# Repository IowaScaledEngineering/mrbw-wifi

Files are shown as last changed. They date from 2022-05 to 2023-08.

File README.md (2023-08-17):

# The Iowa Scaled Engineering MRBW-WIFI ProtoThrottle Bridge

Wireless MRBus to WiFi (802.11) Bridge for ProtoThrottles

# Getting Started

If you're using an ESU CabControl system with the built-in wifi and default configuration (ssid of ESU-WIFI and default password), LNWI, MRC WiFi module, DCC-EX, or Steve Todd's rpi-jmri image, it should just work.  Plug it in, try it out.

If you're using JMRI or any non-default wifi parameters, you'll need to at least set the ssid, password, and mode configuration options.

# Configuration Options

## The Onboard Switches

| Switch | Label | Description |
|---|---|---|
| 1 | Base Addr 16 | Part of setting the ProtoThrottle base address.  Adds 16 to the value if on.  Total sum value of switches 1-5 (the group marked BASE ADDR) must match the base configured in the PT COMM menu. |
| 2 | Base Addr 8 | Part of setting the ProtoThrottle base address.  Adds 8 to the value if on. |
| 3 | Base Addr 4 | Part of setting the ProtoThrottle base address.  Adds 4 to the value if on. |
| 4 | Base Addr 2 | Part of setting the ProtoThrottle base address.  Adds 2 to the value if on. |
| 5 | Base Addr 1 | Part of setting the ProtoThrottle base address.  Adds 1 to the value if on. |
| 6 | A | Not used - for future expansion. |
| 7 | FR | Factory Reset.  If this switch is ON when the unit is powered up or resets, it will overwrite the config.txt file with the factory defaults. |
| 8 | BL | Boot Loader. This is used to upgrade the firmware on the mrbw-wifi.  See the "Firmware Upgrade" section for details on use.  Leave this off for normal operations. |

## Automagic Configuration

The mrbw-wifi, by default, should connect to a good number of things automagically.  ESU CabControl systems using the onboard wifi, Digitrax LNWIs, default DCC-EX builds, and Steve Todd's rpi-jmri images are supported out of the box with no configuration through auto-discovery.

## Manual Configuration

If you do need to configure something different, you'll need to edit the configuration file.  When plugged into a computer via the USB cord, the device presents a mass storage class drive, much like a flash/thumb drive.  On this drive is a single file - config.txt.  Open it with a text editor like Notepad or Notepad++ (or whatever the Mac equivalent is - I have no idea).

The file is just a normal key = value kind of configuration file.  Any line starting with a # is considered a comment and will be ignored.

So, for example, if I want to connect to my layout's network, I might put in three lines:

mode = withrottle
ssid = CRNW Wireless Net
password = TotallyNotMyPassword1

Here's a list of valid parameters in the config.txt file:

| Parameter | Description |
|---|---|
| ssid | If you need to explicitly connect to a wifi network, put its name here.  Do not use quotes or anything else, just the network name as a parameter, even if it has spaces. |
| password  | If you need to connect to a secured wifi network that you specified in the ssid parameter, specify the password here.  If your network specified in ssid does not have a password, just leave an empty value in the password field.  |
| mode | If an ssid is specified, the command station mode must be set.  If the ssid field is not set, the mode parameter can be used to restrict the sort of command station networks that the wifi will automatically discover.  Mode can be `withrottle`, `lnwi`, `dccex`, `esu` currently.  For JMRI, MRC, and most other WiThrottle-compatible servers, use `withrottle`.  For LNWIs, use `lnwi`.  For DCC-EX servers, use `dccex`.  For ESU CabControl or ECoS systems, use `esu`.  |
| serverIP  | Normally the wifi will use mDNS to discover where the server is located.  If for some reason mDNS service discovery does not work, you can explicitly specify the server IP here.  It should be in the form 1.2.3.4 |
| serverPort  | Normally the wifi will use mDNS to discover where the server is located.  If your server does not run on the standard port for the protocol and you have explicitly set the IP address with serverIP, then you should also set the port to connect on with this option. |
| hostname  | If you want the wifi to explicitly use a different hostname when it connects to the network, please specify it here.  By default, it will be mrbw-wifi-XXXX, where XXXX is the last two octets of the MAC address expressed as hexadecimal to make it unique. |
| fastClockSource  | For JMRI, fast time is sent over the withrottle connection.  If you want to send fast time from your JMRI server via the wifi bridge to your ProtoThrottles and/or ISE fast clock remote displays, set this to `cmdstn`.  To disable any fast time being broadcast by the wifi bridge, set it to `none` or omit the parameter entirely. |
| logLevel  | *Advanced Users Only* The wifi bridge exposes a virtual serial port on the USB interface that it uses to send diagnostic logging information about what it's doing.  logLevel controls the verbosity at a global level.  Options in order of increasing verbosity are  `error`, `warn`, `info`, `debug`.  By default, it's set to `info` if not specified.  Unless you're watching the logs and trying to help us debug a specific problem, there's no reason to use this parameter.  In addition, you can use `logLevelCommandStation`, `logLevelMRBus`, or `logLevelSystem` as key values to turn up logging on only a specific part of the code that's having an issue. |

# Firmware Upgrades

The mrbw-wifi is designed to be easily upgradable, both because I know I'm going to have bugs and we're going to add new functionality in the future.

For most users, you'll upgrade via the UF2 bootloader.  Hold the receiver with both hands while it's powered up and plugged into your computer via a USB cord.  Use your left hand to tap the reset button, and immediately flip the BL switch to ON while the LED is purple.  You have 1 second from when you hit the reset button to do this, otherwise the system will boot normally.

If you've done it successfully, a new drive will apear on your machine (named "MRBWWIFI") with three files in it:  current.uf2, index.htm, and info_uf2.txt.

Find the firmware you want to upgrade to (it should be a file ending in .uf2) and copy it to this drive.  The LED should blink yellow and the mrbw-wifi should reboot at the end.  It may throw some sort of error on the computer at the end of the copy - don't worry about that.  Once it's done, turn the BL switch back to off and then hit RESET again.  You should be able to verify a successful upgrade by checking the version on the startup screen matches the version you upgraded to.

# Credits

Credit where credit is due.  This project builds on other open source projects, and without them, this would have taken much, much longer.

First, a credit to Adafruit for developing the [tinyuf2 bootloader](https://github.com/adafruit/tinyuf2) for the ESP32-S2.  Super easy to use, super easy to modify.

Secondly, to Espressif and all the contributors to the Arduino framework for the ESP32 series.  The MRBW-WIFI code is a mix of native ESP-IDF calls and some Arduino stuff, which saved me days if not weeks of figuring out stuff like their WiFi and IP stack.  Eventually we'll get to all native ESP-IDF code, but for now it's an excellent compromise.

Thirdly, to Platform.IO.  Seriously, you guys rock.  A little hard to figure out in spots, particularly where it goes off the rails, but genuinely a huge timesaver for getting up to speed on ESP32 without spending weeks mucking about with trying to figure out setup.  While I wasn't a huge VSCode fan when I started, it's more than earned its keep.

Finally, I'd like to thank ESU, who generously provided us with their protocol documentation, as well as Brett Hoffman and JMRI for the excellent WiThrottle protocol.  

Digitrax, you really need to work on the LNWI.  That thing is a weird glitchy little gremlin. 

# License

The ISE MRBW-WIFI source code is all covered by the GNU General Public License v3.  Full details are in the LICENSE file.
Other stuff, like schematics, PCB layout, and documentation, is Creative Commons CC BY-SA.

# Compiling and Development Thoughts

The MRBW-WIFI is open source software and hardware, and we encourage those interested to tinker with it, fix bugs, add features, or whatever they'd like.  As such, I'm including some thoughts about how to build it.

## Setting up Platform.IO

Install VS Code
https://code.visualstudio.com/download
sudo apt install <name>.deb

Open up VS Code, click on the extensions block on the left side (bottom thing, looks like tetris blocks) and search for "PlatformIO IDE" - click install

Go to "Source Control" (third icon down, left side), clone repository, clone from github (up top), log in, search, yada yada....

It'll pop under a window to pick as to where to clone it.  This is the directory that will hold the directory of the project, not the root level where all the files are going to go.  So for example, if you're cloning mrbw-wifi and you want it in /home/ndholmes/data/projects/mrbw-wifi, you'd pick /home/ndholmes/data/projects here 

Once you pick it, it'll pick up on the fact it needs to install some more underlying components, like the Arduino framework

In your user platformio directory (in Windows, typically C:\Users\(username)\.platformio):

Copy the src-platformio/arduino/ise_mrbwwifi_esp32s2 directory to .platformio/packages/framework-arduinoespressif32/variants
Copy the src-platformio/ise_mrbwwifi_esp32s2.json file to .platformio/platforms/espressif32/boards 

## Building the Bootloader

The bootloader is based off the Adafruit tinyuf2 bootloader.

git clone https://github.com/adafruit/tinyuf2.git
git submodule init
git submodule update

cd lib/esp-idf
./install
. ./export.sh

Copy the src-tinyuf2-bootloader/ise_mrbw_wifi_esp32s2 directory in this project to ports/espressif/boards in the tinyuf2 project
Copy the src-tinyuf2-bootloader/partitions-4MBLA.csv directory in this project to ports/espressif in the tinyuf2 project

cd ports/expressif
make BOARD=ise_mrbw_wifi_esp32s2 all

When you get done, there should be a ports/espressif/_build/ise_mrbw_wifi_esp32s2 directory.  From there, you need tinyuf2.bin and bootloader/bootloader.bin

Copy those into the src/platformio/arduino/ise_mrbwwifi_esp32s2 directory (or .platformio/packages/framework-arduinoespressif32/variants/ise_mrbwwifi_esp32s2 to pick them up immediately) as bootloader-tinyuf2.bin (for bootloader/bootloader.bin) and tinyuf2.bin.

## Building UF2 images

NOTE:  This step shouldn't be necessary any more.  PIO should now be building the UF2 and master bin image in the src/build/release directory.  It's more or less documented so I remember how it works if I have to change things.

Basically the tinyuf2 bootloader confines you to the OTA0 partition.  So it's expecting the base of the UF2 image to be 0x00000000 and it'll add the offset based on the partition table.  That does mean if we ever want to change partitioning, we probably are going to have to do it via esptool.  

python3 ../../util/uf2conv.py -f 0xbfdd4eee -b 0 -c -o mrbwwifi-combined.uf2 firmware.bin

## Building the Master Firmware Image

NOTE:  This step shouldn't be necessary any more.  PIO should now be building the UF2 and master bin image in the src/build/release directory.  It's more or less documented so I remember how it works if I have to change things.

python3 ../../util/join_bins.py mrbwwifi-master.bin 0x1000 ../../../src-platformio/arduino/ise_mrbwwifi_esp32s2/bootloader-tinyuf2.bin 0x8000 partitions.bin 0xE000 ../../../src-platformio/arduino/ise_mrbwwifi_esp32s2/boot_app0.bin 0x10000 firmware.bin 0x2d0000 ../../../src-platformio/arduino/ise_mrbwwifi_esp32s2/tinyuf2.bin

## Initial Flashing

You need to install a version of esptool that supports the EPS32-S2.  IF your python version is 3.7 or greater, just pip install esptool.  Otherwise, you'll have to get a newer version of python, set up a venv, etc.

Step 1: Set BL and FR switch to off (leave rest on), program XBee with ISE parameters

Step 2: Set BL to on, reset, program ESP32-S2 with master firmware image

esptool.py -c esp32s2 -p /dev/ttyACM0 erase_flash

esptool.py -c esp32s2 -p /dev/ttyACM0 write_flash 0 mrbwwifi-[version]-master.bin

Step 3: Turn BL switch off, hit reset button.  Verify LED goes purple, then red, and screen comes up.  The screen takes a while as it's formatting the FAT partition.

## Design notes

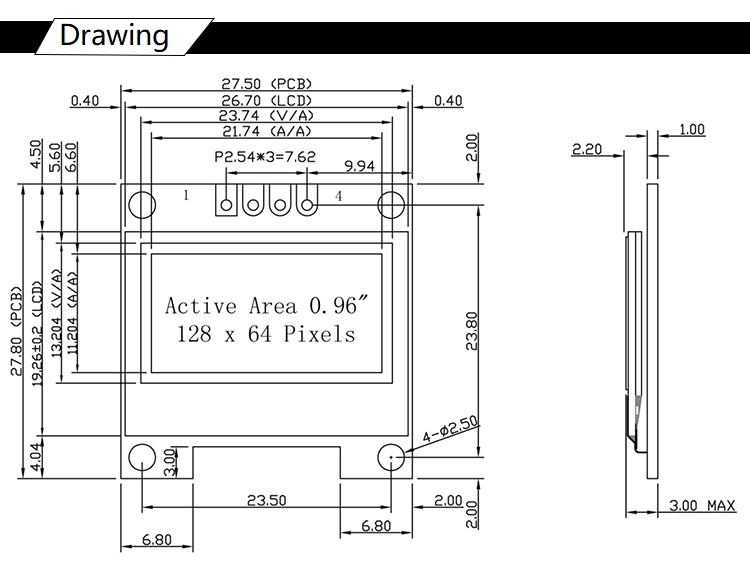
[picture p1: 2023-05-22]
mech/oled-module-dimensions.jpg

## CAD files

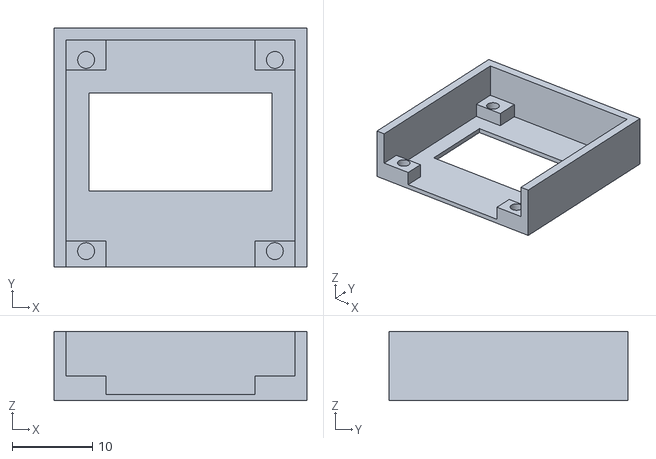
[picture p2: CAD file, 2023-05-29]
mech/screen-top v4.stl
31.5 x 29.8 x 8.60

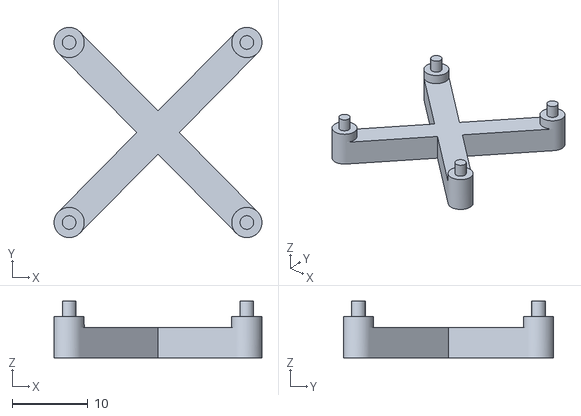
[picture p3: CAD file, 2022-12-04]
mech/screen-spacer v1.stl
27.5 x 27.8 x 7.50

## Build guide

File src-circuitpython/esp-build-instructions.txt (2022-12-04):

1) Make ~/esp

2) In ~/esp, git clone --recursive https://github.com/espressif/esp-idf.git

3) Get IDF dependencies:
sudo apt-get install git wget flex bison gperf python3 python3-venv cmake ninja-build ccache libffi-dev libssl-dev dfu-util libusb-1.0-0 gettext

4) Switch to a stable release: git checkout v4.4.2

5) In ~/esp/esp-idf, run ./install.sh
. ./export.sh

# Hack to work around bug
pip install "jinja2<3.1"  "itsdangerous<2.1"

6) In ~/esp,
git clone https://github.com/adafruit/circuitpython.git
git checkout 7.3.x
make fetch-submodules

pip3 install --upgrade -r requirements-dev.txt
pip3 install --upgrade -r requirements-doc.txt
pip3 install esptool

make -C mpy-cross

cd ports/espressif

Install ISE MRBW-WIFI Board files
copy mrbw-wifi/src/circuitpython-build/ise_mrbw_wifi_esp32s2 to circuitpython/ports/espressif/boards/

Install stuff to make factory reset filesystem
copy mrbw-wifi/src/circuitpython-build/filesystem.c to circuitpython/supervisor/shared
run make-header.py in mrbw-wifi/src to generate mrbwwifi-init.h
Copy mrbwwifi-init.h to circuitpython/supervisor/shared

Build firmware image
Go into circuitpython/ports/espressif
. ~/esp/esp-idf/export.sh  (to set the IDF environment stuff right, if you haven't already)
make BOARD=ise_mrbw_wifi_esp32s2 clean
make BOARD=ise_mrbw_wifi_esp32s2

If this succeeds, you'll have a firmware.bin file in build-ise_mrbw_wifi_esp32s2

Unplug mrbw-wifi, set BL switch, plug in
sudo chmod 0666 /dev/ttyACM0 ; esptool.py --port /dev/ttyACM0 --after=no_reset write_flash 0x0 build-XXX/firmware.bin

Unplug, turn off BL switch, replug.

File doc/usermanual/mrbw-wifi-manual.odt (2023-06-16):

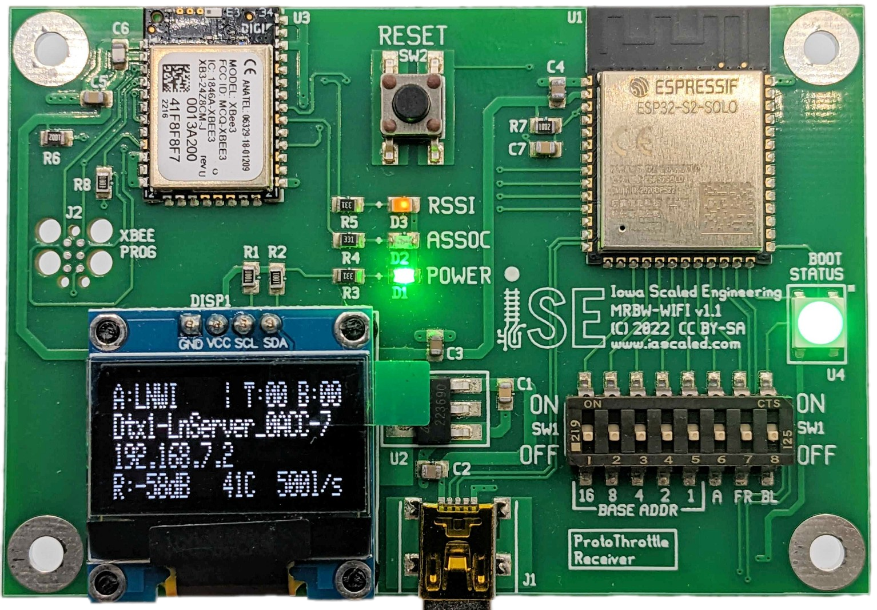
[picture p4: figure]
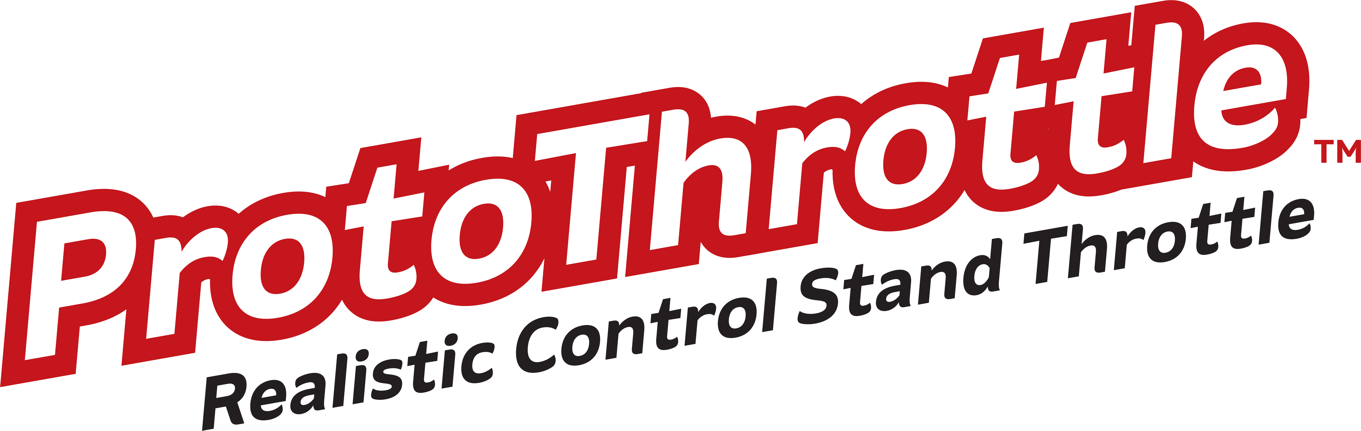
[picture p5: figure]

Receiver for WiFi Systems
v1.0

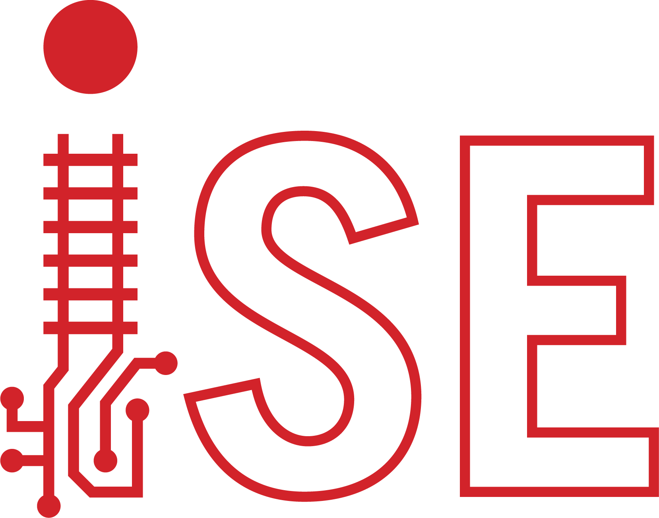
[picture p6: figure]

IOWA SCALED ENGINEERING – ELECTRONICS MADE EASY

# Getting Started

For most users, getting started will just be a matter of powering up the unit using the included USB cable and power supply. If you need to change your base address from the default of zero, set the DIP switches to match what you have configured in your ProtoThrottle.

The new receiver should find Digitrax LNWIs, DCC-EX systems, MRC WiFi modules, and ESU CabControl systems in their default configurations automatically and attach to them with no user intervention.

If your LNWI has a password, or you’re attaching to a network to connect to a JMRI WiThrottle server, you’ll need to use a text editor to set a few values in the config.txt file. Plug the USB cable into your computer instead and see the instructions under “WiFi / Network Configuration”.

# Switch Configuration

There are eight switches located to the right of the screen. Moving the switch up (away from the edge of the board with the USB connector) turns it “ON”, and moving the switch down (towards the edge) turns it “OFF”.

Switch | Function
BASE ADDR 16, 8, 4, 2, 1 | Set the radio base address of this receiver for the ProtoThrottle. Add the value(s) of the switches that are in the ON position to get the address. Program this value into the ProtoThrottle using the COMM CFG – BASE ADR menu. The base address should not be the same on any receivers within radio range of each other. Example: If you want base address 5, set switch 1 and 4 to “on”.
A | Reserved for future use.
FR | Factory Reset – If this switch is ON when the unit is powered up (or when the reset button is pressed), the receiver will restore the config.txt file to its factory default state.
BL | Bootloader – LEAVE THIS SWITCH OFF While you won’t break anything by turning it on, having this switch on will cause the device to come up in various bootloader modes that can be used to upgrade firmware or recover a bricked device. See the “Firmware Updates” section for details.

# WiFi / Network Configuration

For systems using ESU CabControl, Digitrax LNWI, DCC-EX or MRC WiFi wireless systems in their default configuration, no configuration changes should be needed. The receiver should automatically find your network and connect to it.

If you are using a JMRI WiThrottle server, have a password on your LNWI, or other more complex configuration, some adjustments may be needed.

Plug the ProtoThrottle WiFi Reciever into your computer and it should appear as a drive. On it, you should see a file called “config.txt”. Open it with a basic text editor (Notepad, Notepad++, TextEdit, etc.), make appropriate changes, and then save it again. Saving the file will cause the receiver to restart, reloading your changes.

The file has a simple key = value format per line – no quotes or anything else are needed or wanted. The keys and values are case sensitive, however, and must be typed accurately. Any line without a value will be ignored.

Key | Value(s) | Usage
mode | lnwi withrottle esu dccex | Configure which type of server. ‘lnwi’ is specifically for Digitrax LNWIs , and ‘dccex’ is specifically for DCC-EX systems. All other WiThrottle-compatible servers should use ‘withrottle’. ESU CabControl systems use ‘esu’. If this option is specified without specifying ssid and password, it will limit network automatic discovery to only those types of servers (LNWIs, DCC-EXs and ESUs, primarily).
ssid | (your wireless network name) | Name of your WiFi network. If you specify this, please also specify mode and password.
password | (your wireless network password) | Your WiFi network password. Leave blank for open/unsecured networks.
serverIP | (server IP address) | To save time searching for your WiThrottle server on a network, a specific server IP or address can be specified here.
serverPort | (server port) | Normally the server port will be assumed from the server type. However, if you want to run your WiThrottle or ESU server on a non-standard port, it can be specified here.
fastClockSource | none cmdstn | Some WiThrottle connections are capable of sending fast time to the throttles. Set this to “cmdstn” in order to use the command station fast time. Leave this at none to use other fast time sources.

# Main Screen

In order to show you a variety of status information, the receiver has a small OLED screen on board. While the actual screen is just black and white, the various fields are color highlighted to help explain them.

A:LNWI / T:01 B:00

Dtx1-LnServer_0ACC-7

L:192.168.7.1

R:-78dB 48C 525l/s

Element | Meaning
A: | Command station discovery method. A=automatic, C=from config.txt
LNWI | Command station type. LNWI, ESU, WTHR, DCCX, or NONE
/ | Spinner – will spin every second to confirm the receiver is still operating.
T:01 | Number of throttles actively connected to the receiver.
B:00 | Base address selected via the switches to the right of the screen. If another base at the same address is within range, the B will be changed to an asterisk.
Dtx1-Ln... | Network SSID the receiver is attached to, or (Searching...) if it hasn’t yet found a network
L:192.168.7.1 | If L is the first character, the IP address of the receiver or (Not Connected) if the receiver has not yet connected to a WiFi network. If C is the first character, the IP address of the command station. Switches between the two every two seconds.
R:-78dB | WiFi signal strength. The more negative the number, the less signal strength.
48C | Current temperature of the receiver CPU.
525l/s | Loops per second – how fast the software is running and processing incoming requests from the command station and the throttle.

# Boot Status LED

On the right side of the board above the switches is a large, multi-color LED that is used to communicate status of the board at a glance, and in places where the board isn’t able to use the main screen to communicate.

During startup, the LED will briefly go purple. This indicates that the BL switch can be flipped to enter the firmware update process. See the next section for details.

During normal operation, the light will be red if the device hasn’t found a wireless network to join, yellow once it’s found the network but hasn’t found the command station / withrottle server, and green once it’s happily connected. If the light starts blinking between blue and green, it means that another conflicting ProtoThrottle receiver on the same base address is within range.

# Firmware Updates

From time to time, we may release firmware updates to add new functionality or fix bugs in the receiver. In order to update, you’ll download UF2 firmware from our website. Plug your receiver into your computer’s USB port. Holding the receiver with your left hand, press “RESET” and immediately flip the BL switch with your right hand while the LED is purple. You only have one second to do it, so it’s best to have your fingernail on the switch before hitting reset. If successful, you’ll see a drive come up with three files – current.uf2, index.htm, and info_uf2.txt. Copy the UF2 firmware file that you downloaded onto this drive. The status LED will blink from green to yellow and eventually the receiver should reset. Once complete, turn the BL switch back off and hit RESET again, and you should see the new firmware version on the boot screen.

# Factory Reset

If your receiver ever gets in a state where your config.txt is messed up or your computer cannot read it, you can restore it to factory condition by setting the FR switch to ON and briefly pushing the reset button. Your receiver will reboot, the status LED will turn blue as it overwrites the old config.txt with a fresh copy (this may take several seconds longer than a normal startup), and then will start up normally. Don’t forget to turn the FR switch back off once the receiver has booted, or it will overwrite the config.txt file again!

Like almost all Iowa Scaled Engineering products, the
MRBW-WIFI is open source hardware and software. Source code is made available under the GNU General Public License v3, and all other documentation under Creative Commons. All of our hardware design files and source code are available from our Github account:

https://github.com/IowaScaledEngineering/mrbw-wifi

We would very much like to acknowledge and thank some other open source projects that have made developing the MRBW-WIFI significantly easier: Adafruit’s tinyuf2 bootloader, the Espressif ESP32-S2 Arduino framework, and the Platform.IO team who have built a great embedded development environment.

Also, ISE would like to thank ESU for providing detailed protocol information about how to connect to their command station, as well as Brett Hoffman and the JMRI team for making the excellent WiThrottle protocol a standard.

ProtoThrottle WiFi Receiver
Model: MRBW-WIFI, Hardware Version: 1.1
Iowa Scaled Engineering, LLC
support@iascaled.com
This product is not a toy. For ages 14 and over.
Contains FCC ID: MCQ-XBEE3 and 2AC7Z-ESPS2SOLO2U
This device complies with part 15 of the FCC Rules. Operation is subject to the following two conditions: (1) This device may not cause harmful interference, and (2) this device must accept any interference received, including interference that may cause undesired operation. Changes or modification to the device could void the user’s authority to operate the equipment.
Contains IC: 1846A-XBEE3 and IC: 21098-ESP32S2SOLO
This device complies with Industry Canada’s license-exempt RSSs. Operation is subject to the following two conditions:
(1) This device may not cause interference; and (2) This device must accept any interference, including interference that may cause undesired operation of the device.
Le présent appareil est conforme aux CNR d’Industrie Canada applicables aux appareils radio exempts de licence. L’exploitation est autorisée aux deux conditions suivantes:
(1) l’appareil ne doit pas produire de brouillage, et (2) l’utilisateur de l’appareil doit accepter tout brouillage radioélectrique subi, même si le brouillage est susceptible d’en compromettre le fonctionnement. Changes or modification to the device could void the user’s authority to operate the equipment. Des changements ou des modifications à l’appareil pourraient annuler l’autorité de l’utilisateur à utiliser l’équipement

Visit the Iowa Scaled Engineering website

and store to learn more about our full line

of model railroad electronics.

www.iascaled.com

www.protothrottle.com

© 2023 Iowa Scaled Engineering, LLC

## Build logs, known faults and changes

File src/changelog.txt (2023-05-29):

MRBW-WIFI Firmware Changelog

-----------------------------------------------
1.0.6 (2c3e76) - 29 May 2023

BUG FIX: FR switch didn't actually cause a factory reset of the internal
 configuration drive / config.txt file.  Also turn the status LED blue to indicate
 that the internal filesystem is being rewritten to factory defaults (in all cases, 
 not just when the FR switch is set)

-----------------------------------------------
1.0.5 (e221c8) - 29 May 2023

BUG FIX: Fix issue where receiver would crash when disconnecting from a command
 station if the wifi network had failed / gone away.

FEATURE: Better support for DCC-EX by separating it out as its own command station
 type and implementing specific quirks (such as not supporting force function 'f')

-----------------------------------------------
1.0.4 (c5984b) - 22 May 2023

FEATURE: Added EVENT handling to the ESU code, such that if another 
 throttle updates the same engine selected on the PT, we'll respond appropriately.

FEATURE: Added JMRI fast clock support.  Setting "fastClockSource = cmdstn" 
 in the configuration file will tell the mrbw-wifi to use fast time from any sort 
 of withrottle server.  Yes, that includes the LNWI.  However, the LNWI doesn't 
 disappoint as the glitchy little gremlin that it is, and its support for sending 
 fast time seems to be "special" at best and broken at worst.  However, JMRI 
 works flawlessly as best I can tell.

FEATURE:  Added duplicate PT receiver detection.  If you have two PT receivers 
 on the same base address, you'll now get an asterisk instead of a B in front 
 of the base addr on the screen, and the LED will blink green -> cyan -> green 
 on a 1s interval.

FEATURE: Added display of both the receiver's IP address and the command station /
 server that it's trying to connect to.  An L: on the front end means it's the 
 local address, a C: means it's the command station IP/port.  These cycle on 
 a 2 second interval so you can see both.

CLEANUP: Cleaned up serial console logging and added the ability to set the log 
 level in the config.txt file so that you can turn up the logging if we run into 
 a problem we can't duplicate.  

-----------------------------------------------
** 1.0.3 (c2c668) - 20 May 2023

BUG FIX: Withrottle driver directions reversed

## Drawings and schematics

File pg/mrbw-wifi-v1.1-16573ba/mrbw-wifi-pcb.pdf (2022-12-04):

# mrbw-wifi.pcb

# 1. Table of Contents (This Page) Created on Sat Oct 15 22:01:38 2022

# 2. top 3. bottom 4. outline 5. plated-drill 6. unplated-drill 7. componentmask 8. soldermask 9. topsilk 10. bottomsilk 11. toppaste 12. topassembly 13. bottomassembly 14. fab

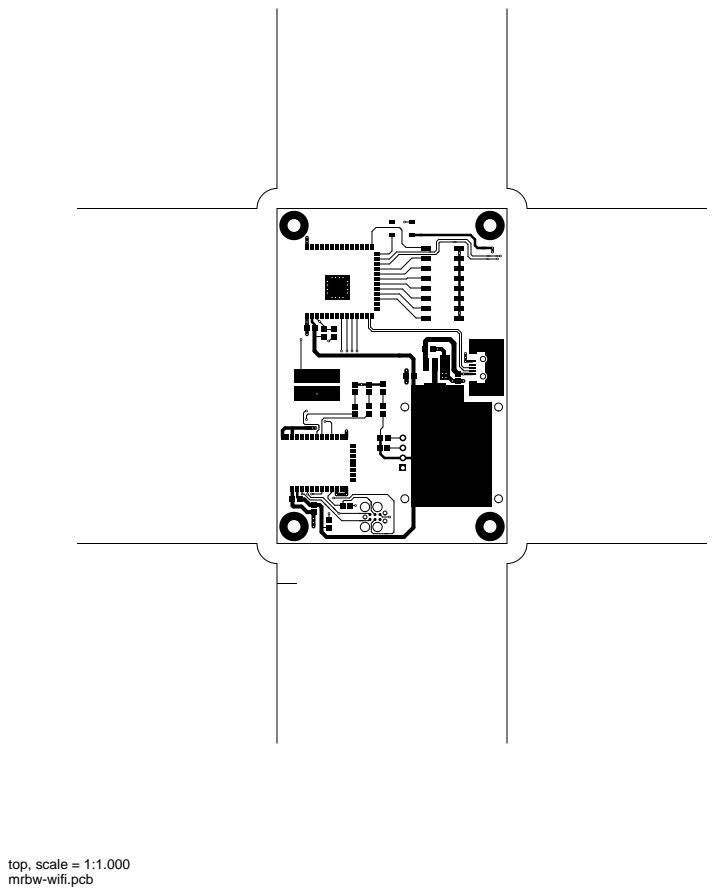
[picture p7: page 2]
top, scale = 1:1.000

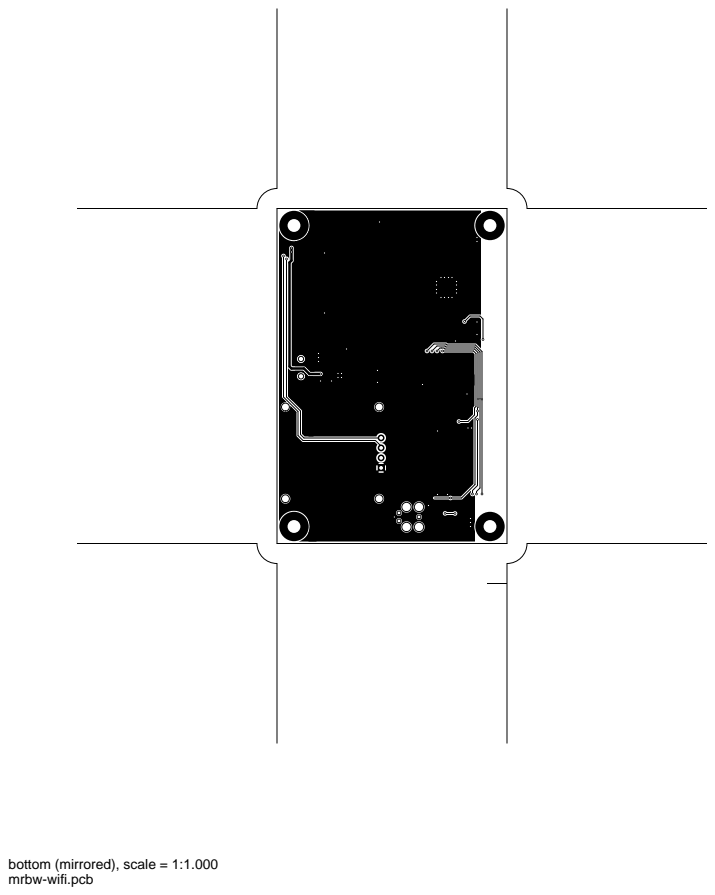
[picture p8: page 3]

bottom (mirrored), scale = 1:1.000

outline, scale = 1:1.000

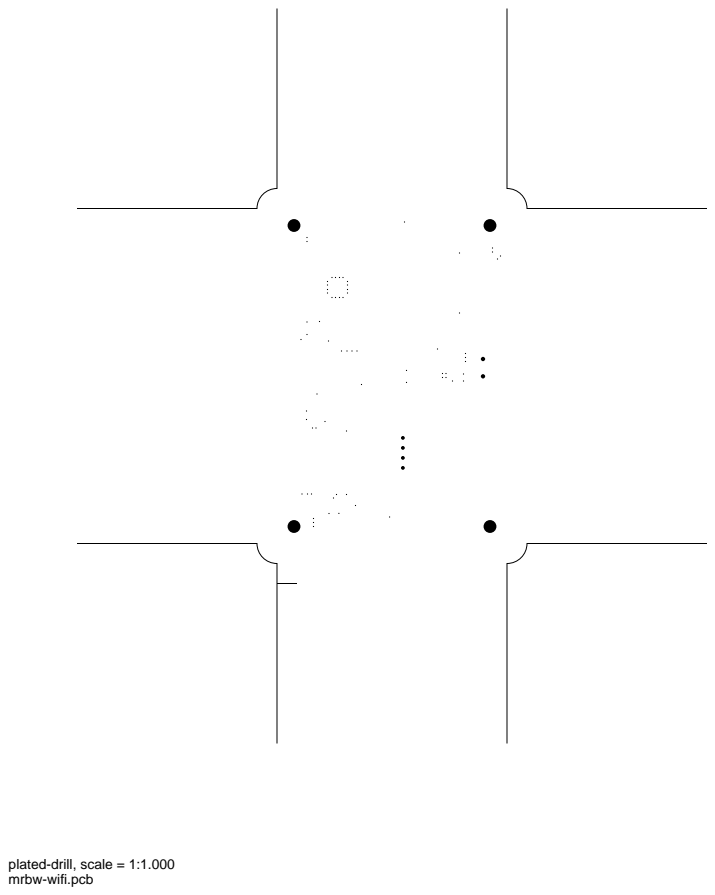
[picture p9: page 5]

plated-drill, scale = 1:1.000

unplated-drill, scale = 1:1.000

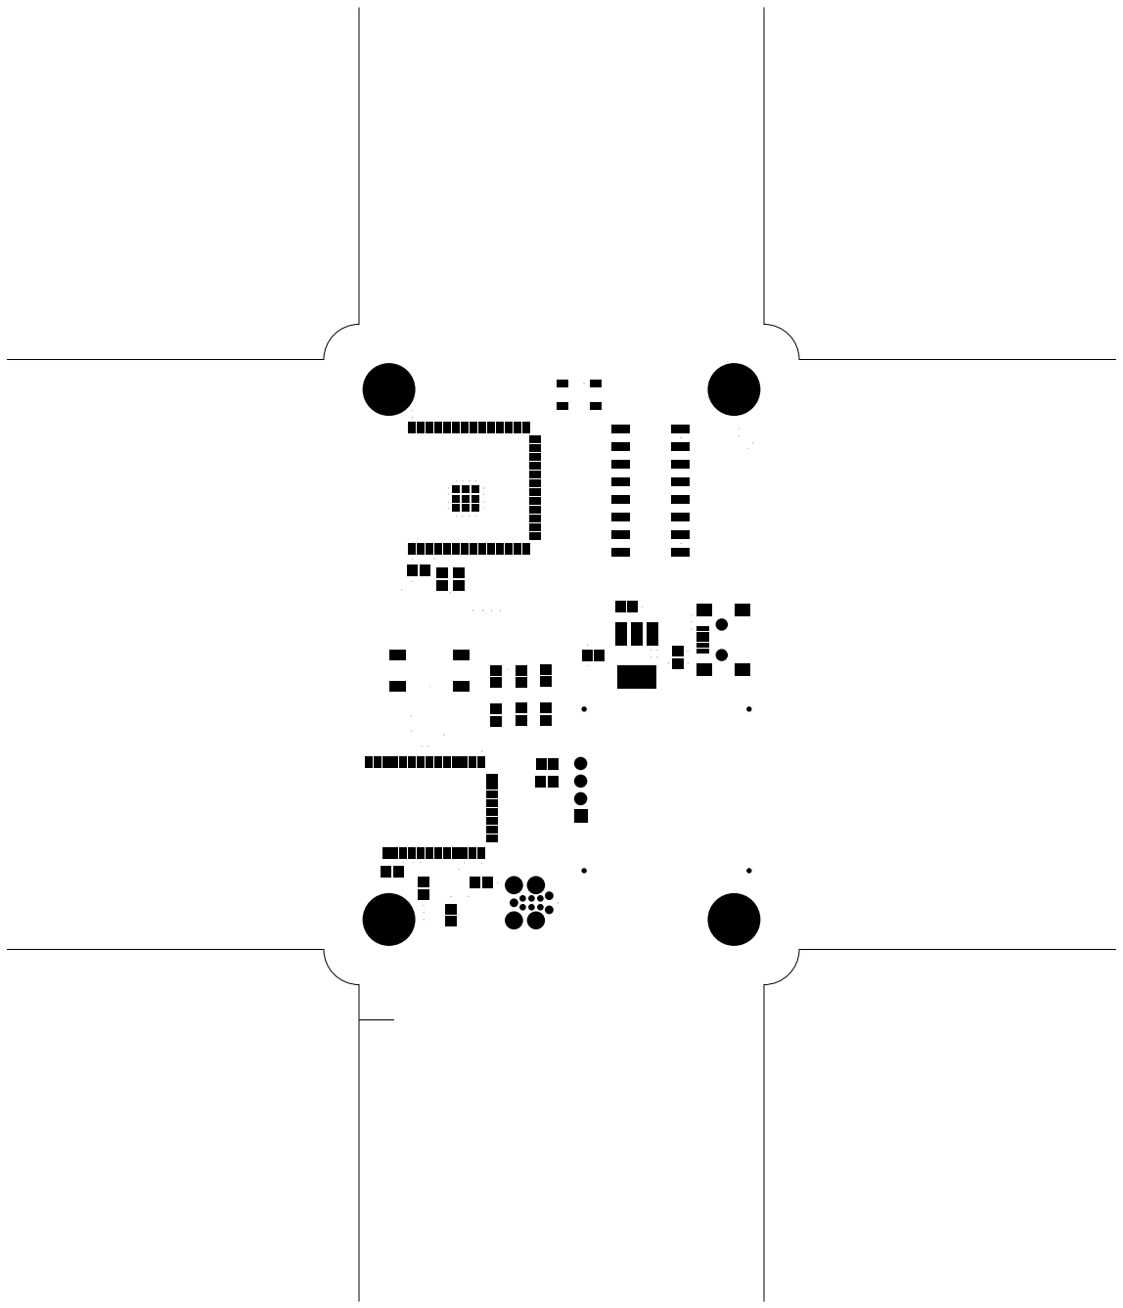
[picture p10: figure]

topmask, scale = 1:1.000

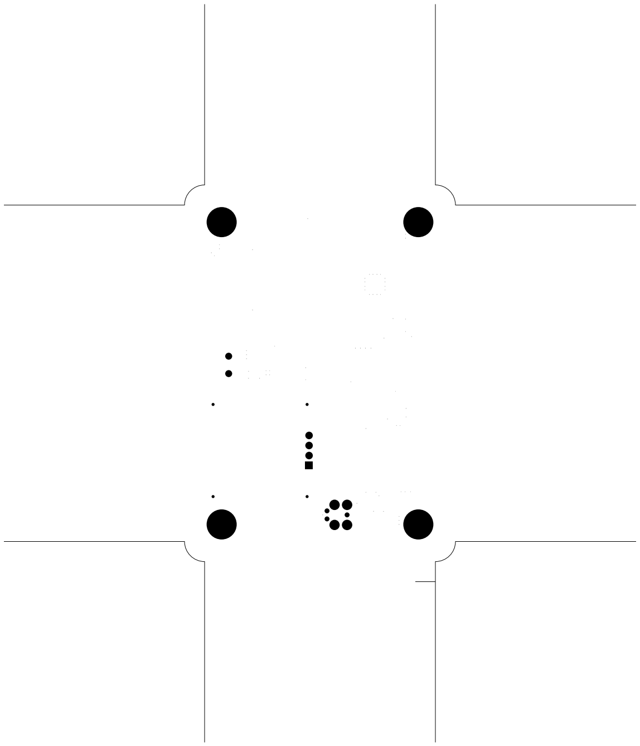
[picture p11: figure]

bottommask (mirrored), scale = 1:1.000

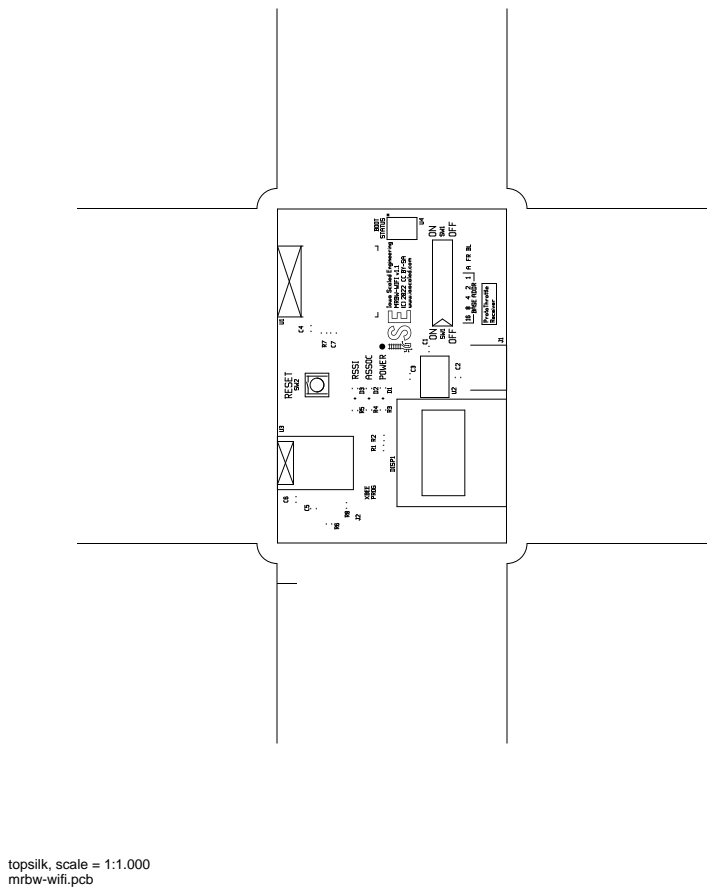
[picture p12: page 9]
topsilk, scale = 1:1.000

bottomsilk (mirrored), scale = 1:1.000

toppaste, scale = 1:1.000

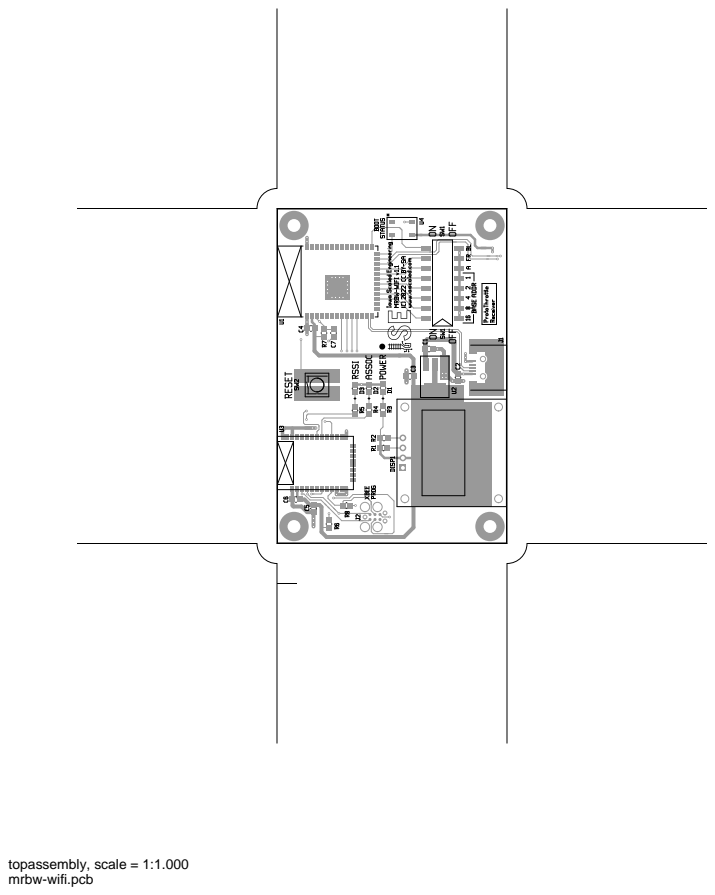
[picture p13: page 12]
topassembly, scale = 1:1.000

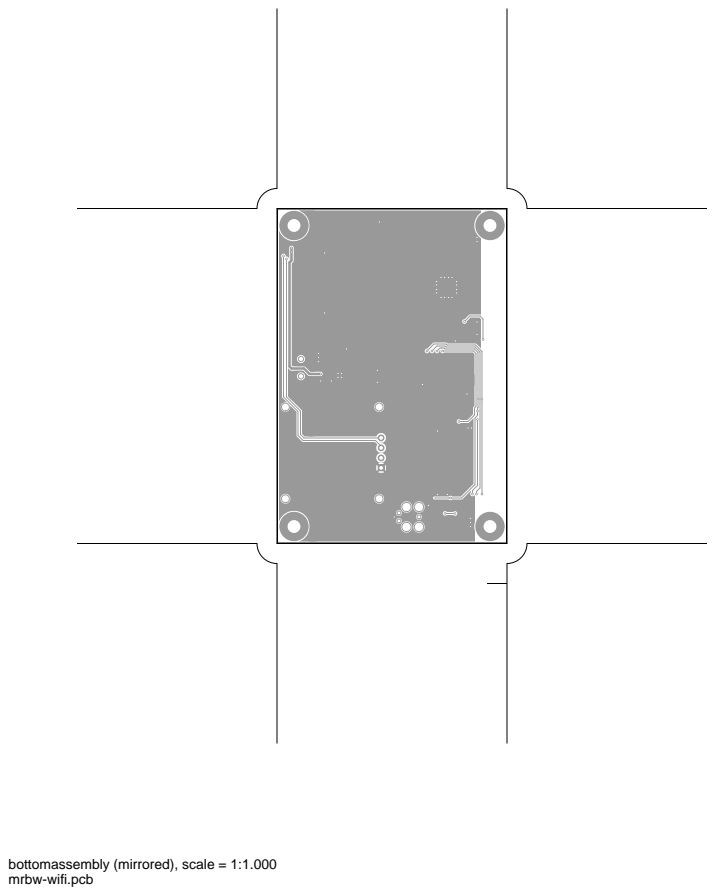
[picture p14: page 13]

bottomassembly (mirrored), scale = 1:1.000

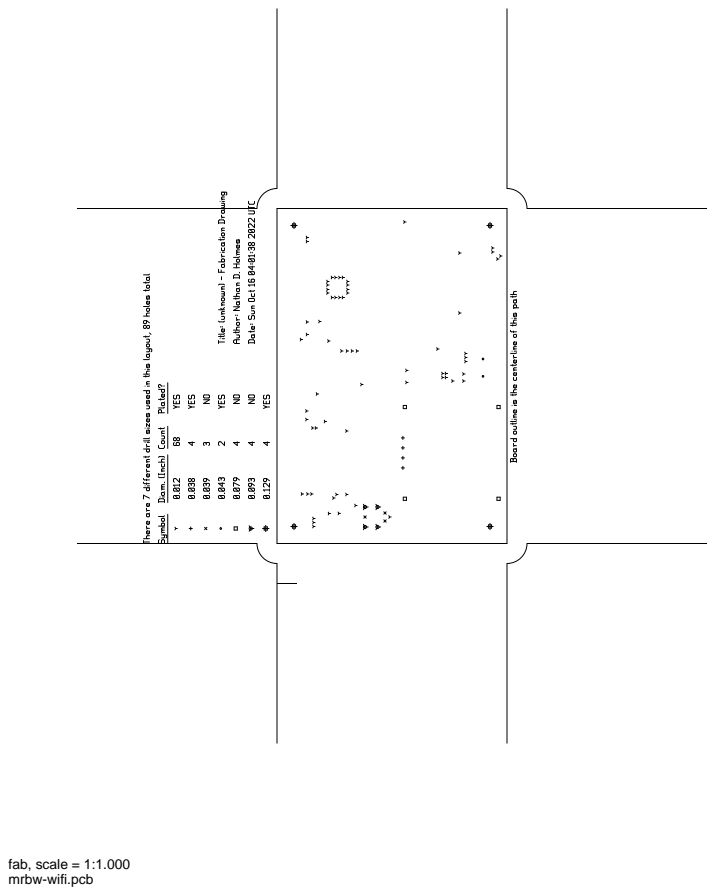
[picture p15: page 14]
fab, scale = 1:1.000

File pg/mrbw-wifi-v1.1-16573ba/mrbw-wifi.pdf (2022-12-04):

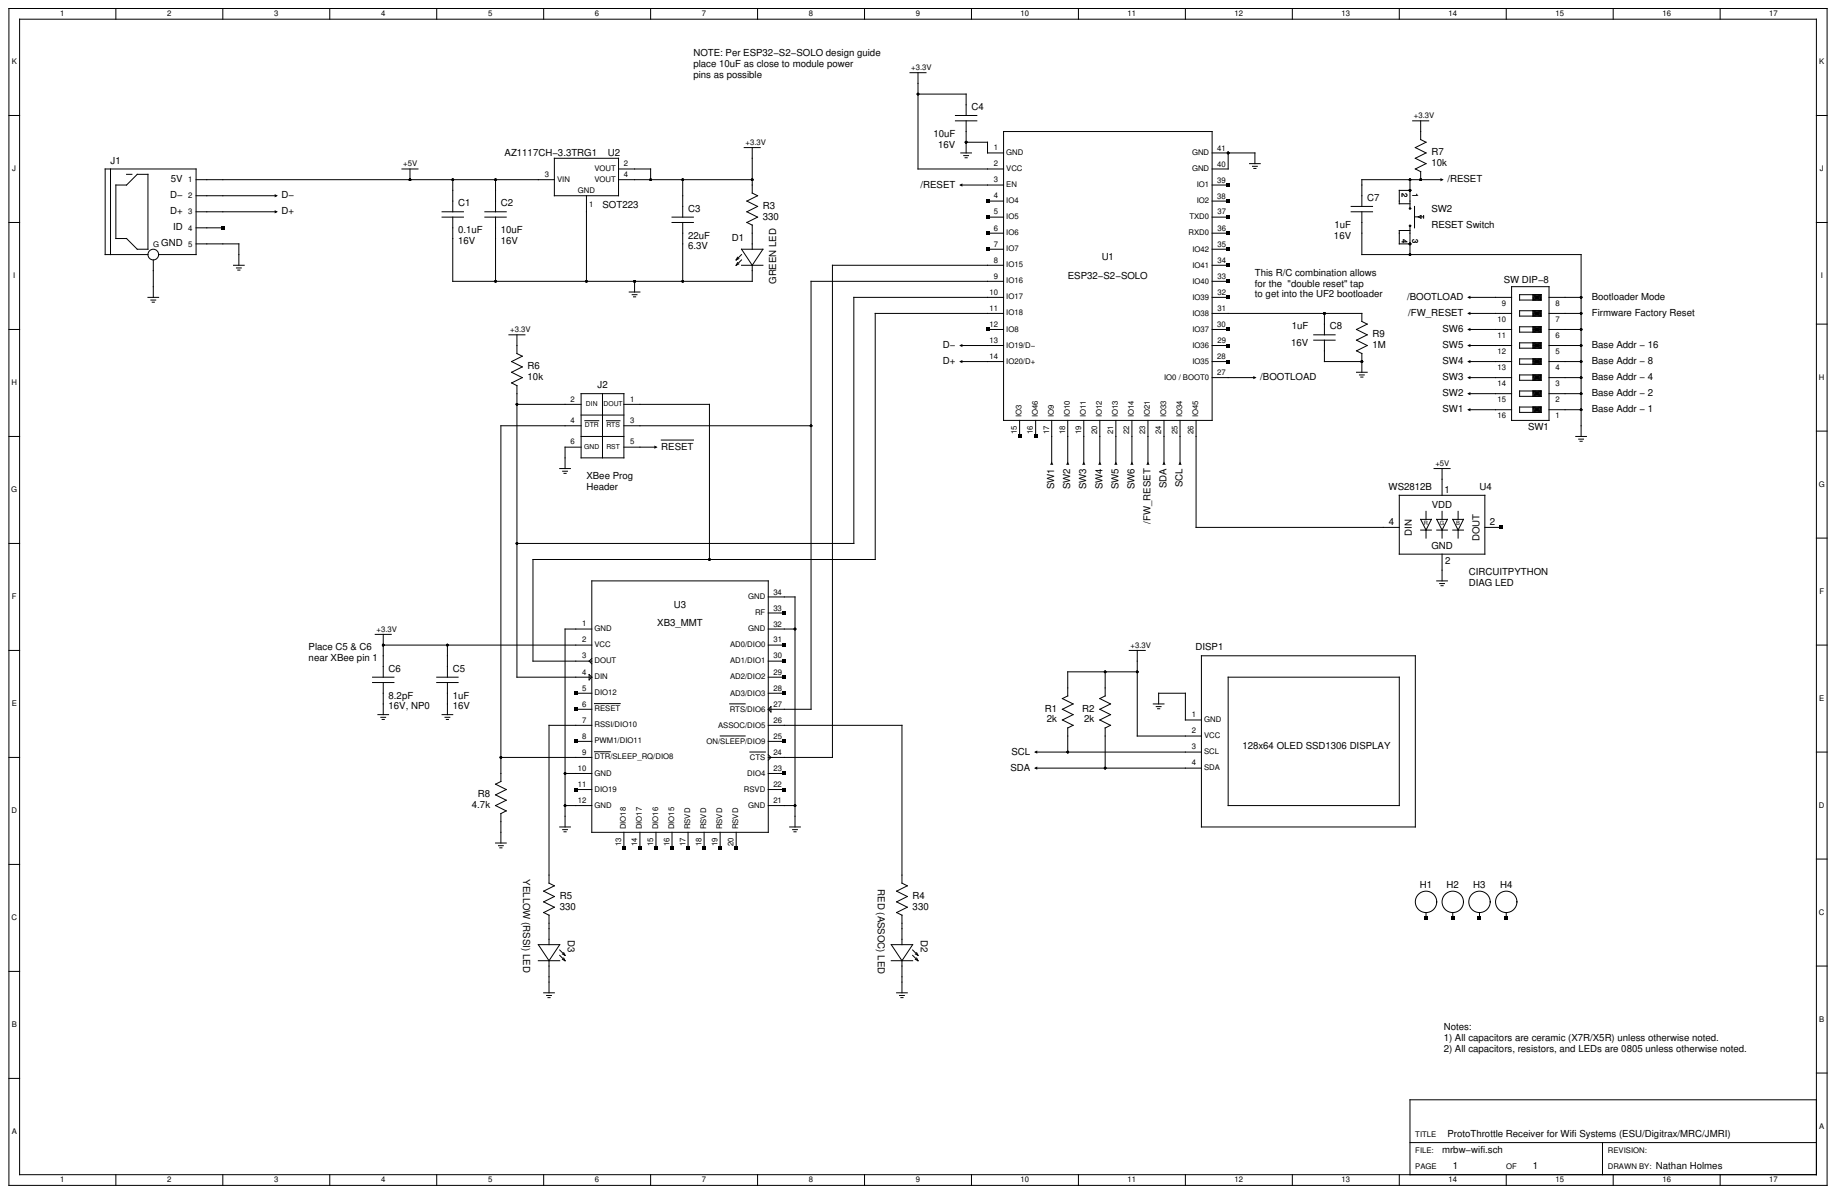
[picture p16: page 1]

NOTE: Per ESP32−S2−SOLO design guide
place 10uF as close to module power
pins as possible

This R/C combination allows
for the "double reset" tap
to get into the UF2 bootloader

Notes:
1) All capacitors are ceramic (X7R/X5R) unless otherwise noted.
2) All capacitors, resistors, and LEDs are 0805 unless otherwise noted.

ProtoThrottle Receiver for Wifi Systems (ESU/Digitrax/MRC/JMRI)
mrbw−wifi.sch

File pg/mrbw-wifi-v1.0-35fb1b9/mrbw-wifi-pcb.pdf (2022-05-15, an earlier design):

# mrbw-wifi.pcb

# 1. Table of Contents (This Page) Created on Sat May 14 12:06:42 2022

# 2. top 3. bottom 4. outline 5. plated-drill 6. unplated-drill 7. componentmask 8. soldermask 9. topsilk 10. bottomsilk 11. toppaste 12. topassembly 13. bottomassembly 14. fab

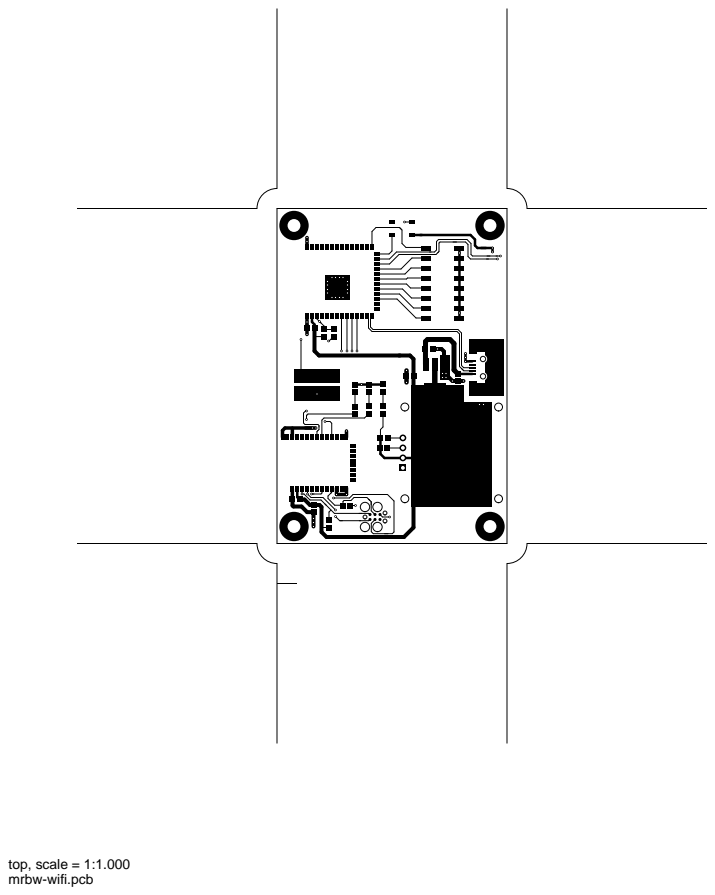
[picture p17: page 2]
top, scale = 1:1.000

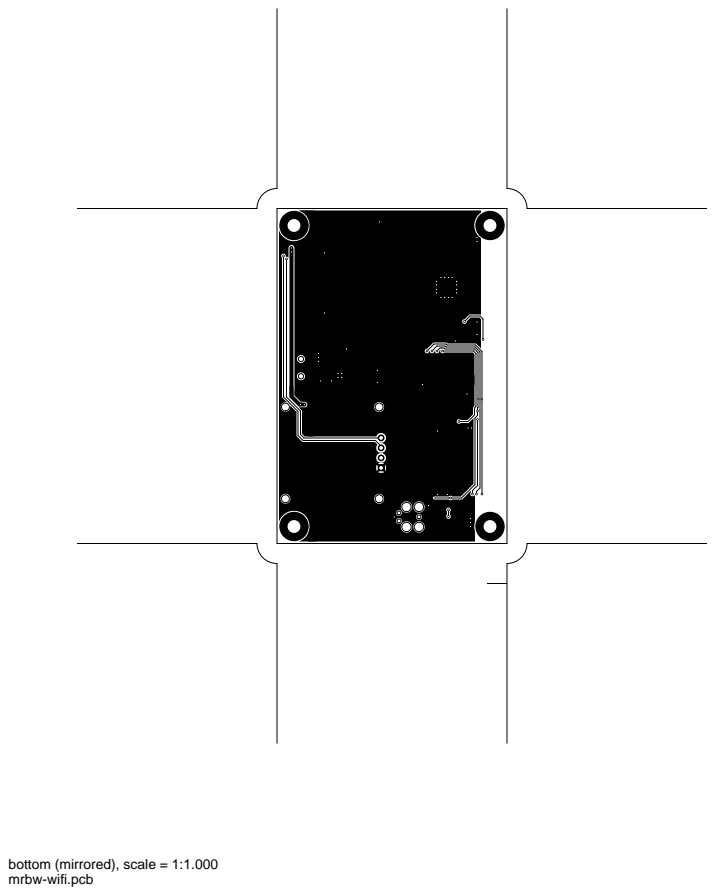
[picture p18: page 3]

bottom (mirrored), scale = 1:1.000

outline, scale = 1:1.000


plated-drill, scale = 1:1.000

unplated-drill, scale = 1:1.000


topmask, scale = 1:1.000


bottommask (mirrored), scale = 1:1.000

topsilk, scale = 1:1.000

bottomsilk (mirrored), scale = 1:1.000

toppaste, scale = 1:1.000

topassembly, scale = 1:1.000


bottomassembly (mirrored), scale = 1:1.000

fab, scale = 1:1.000

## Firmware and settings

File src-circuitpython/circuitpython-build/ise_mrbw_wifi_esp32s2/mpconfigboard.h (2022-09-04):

/*
 * This file is part of the MicroPython project, http://micropython.org/
 *
 * The MIT License (MIT)
 *
 * Copyright (c) 2019 Scott Shawcroft for Adafruit Industries
 *
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
 * THE SOFTWARE IS PROVIDED "AS IS", WITHOUT WARRANTY OF ANY KIND, EXPRESS OR
 * IMPLIED, INCLUDING BUT NOT LIMITED TO THE WARRANTIES OF MERCHANTABILITY,
 * FITNESS FOR A PARTICULAR PURPOSE AND NONINFRINGEMENT. IN NO EVENT SHALL THE
 * AUTHORS OR COPYRIGHT HOLDERS BE LIABLE FOR ANY CLAIM, DAMAGES OR OTHER
 * LIABILITY, WHETHER IN AN ACTION OF CONTRACT, TORT OR OTHERWISE, ARISING FROM,
 * OUT OF OR IN CONNECTION WITH THE SOFTWARE OR THE USE OR OTHER DEALINGS IN
 * THE SOFTWARE.
 */

// Micropython setup

#define MICROPY_HW_BOARD_NAME       "ISE MRBW-WIFI ESP32S2"
#define MICROPY_HW_MCU_NAME         "ESP32S2"

#define MICROPY_HW_NEOPIXEL (&pin_GPIO45)

#define DEFAULT_I2C_BUS_SCL (&pin_GPIO34)
#define DEFAULT_I2C_BUS_SDA (&pin_GPIO33)

#define DEFAULT_SPI_BUS_SCK (&pin_GPIO36)
#define DEFAULT_SPI_BUS_MOSI (&pin_GPIO35)
#define DEFAULT_SPI_BUS_MISO (&pin_GPIO37)

#define DEFAULT_UART_BUS_RX (&pin_GPIO5)
#define DEFAULT_UART_BUS_TX (&pin_GPIO6)

#define DOUBLE_TAP_PIN (&pin_GPIO38)

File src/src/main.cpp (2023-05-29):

#include <Arduino.h>
#include <Wire.h>
#include "WiFi.h"
#include "FFat.h"
#include "esp_task_wdt.h"

SET_LOOP_TASK_STACK_SIZE(62 * 1024);

// Include drivers for MRBW-WIFI hardware
#include "commonFuncs.h"
#include "versions.h"
#include "mrbus.h"
#include "systemState.h"
#include "switches.h"
#include "msc.h"
#include "display.h"
#include "ws2812.h"
#include "periodicEvent.h"
#include "MRBusThrottle.h"
#include "WiThrottle.h"
#include "ESUCabControl.h"
#include "Clock.h"
#include "esp32s2/rom/rtc.h"
#include <ESPmDNS.h>

#define PIN_SDA  33
#define PIN_SCL  34

ISE_MSC msc;
I2CDisplay display;
Switches switches;
SystemState systemState;
MRBus mrbus;
MRBusThrottle throttles[MAX_THROTTLES];

typedef enum 
{
  STATE_STARTUP               = 0x00,
  STATE_DRAW_SPLASH_SCREEN    = 0x10,
  STATE_WAIT_SPLASH_SCREEN    = 0x11,
  STATE_MAIN_LOOP             = 0x80
} loopState_t;

loopState_t mainLoopState = STATE_STARTUP;
PeriodicEvent tmrStatusScreenUpdate;
PeriodicEvent tmrSplashScreen;

void setup() 
{
  Serial.begin();
  systemState.resetReason = rtc_get_reset_reason(0);
  switches.setup();
  Wire.setPins(PIN_SDA, PIN_SCL);
  Wire.setClock(400000UL);
  Wire.begin();
  mrbus.begin();

  esp_task_wdt_init(WDT_TIMEOUT, true); //enable panic so ESP32 restarts
  esp_task_wdt_add(NULL); //add current thread to WDT watch
  esp_task_wdt_reset();
  ws2812Set(WS2812_RED);

  // Try to mount the FFat partition, format if it can't find it
  systemState.isFSConnected = FFat.begin(true);

  // See if we have a config file.  If we don't, just blow away the partition
  if (systemState.isFSConnected || switches.factoryResetGet())
  {
    File f = FFat.open(CONFIG_FILE_PATH);
    if (!f || f.isDirectory() || switches.factoryResetGet())
    {
      ws2812Set(WS2812_BLUE);
      // Shut it down, reformat, start over - nuclear approach!
      FFat.end();
      FFat.format(true);
      systemState.isFSConnected = FFat.begin(true);
      if (systemState.isFSConnected)
        systemState.configWriteDefault(FFat);
      ws2812Set(WS2812_RED);
    }
  }

  // Read configuration from FAT partition before 
  //  we open it up to allow the host computer to write to it
  systemState.configRead(FFat);

  mrbus.debugLevelSet(systemState.debugLvlMRBus);

  // Initialize the throttle array - needs to be after reading configuration
  for(uint32_t thrNum=0; thrNum<MAX_THROTTLES; thrNum++)
  {
    throttles[thrNum].initialize(MRBUS_THROTTLE_BASE_ADDR + thrNum, systemState.debugLvlMRBus);
  }

  // Start mass storage class driver.  From here on out, we should be read-only on
  // the mrbw-wifi side
  msc.start();

  // Initialize wifi radio and disconnect from anything we might be connected to
  //  as well as set some basic stuff - hostname, always sort by signal strength, etc.
  WiFi.mode(WIFI_STA);
  WiFi.setHostname(systemState.hostname);
  WiFi.disconnect();
  WiFi.setSortMethod(WIFI_CONNECT_AP_BY_SIGNAL);

  esp_task_wdt_reset();
  // Start the display
  display.setup(&Wire, 0x3C);

  esp_task_wdt_reset();
  tmrStatusScreenUpdate.setup(1000); // Status screen updates every 1s
}

void drawSplashScreen(SystemState& state)
{
  char buffer[32];
  display.clrscr();
  display.putstr("Iowa Scaled", 0, 0);
  display.putstr("Engineering", 0, 1);
  display.putstr("MRBW-WIFI  ", 0, 2);
  snprintf(buffer, sizeof(buffer), "%d.%d.%d %6.6s", MAJOR_VERSION, MINOR_VERSION, DELTA_VERSION, GIT_REV);
  display.putstr(buffer, 0, 3);
  
  snprintf(buffer, sizeof(buffer)-1, "%02X%02X", state.macAddr[4], state.macAddr[5]);
  display.putstr(buffer, 15, 4);
  
  display.drawISELogo();  
  display.refresh();
}

#define TIME_FLAGS_DISP_FAST       0x01
#define TIME_FLAGS_DISP_FAST_HOLD  0x02
#define TIME_FLAGS_DISP_REAL_AMPM  0x04
#define TIME_FLAGS_DISP_FAST_AMPM  0x08

bool sendMRBusTimePacket(SystemState& systemState, MRBus& mrbus)
{
  MRBusPacket timePkt;
  // If the fast clock isn't enabled, don't send a time packet
  if (!systemState.fastClock.isEnabled())
    return false;

  timePkt.src = systemState.mrbusSrcAddrGet();
  timePkt.dest = 0xFF;
  timePkt.len = 14;
  timePkt.data[0]  = 'T';
  timePkt.data[1]  = 0; // Real hours
  timePkt.data[2]  = 0; // Real minutes
  timePkt.data[3]  = 0; // Real seconds
  timePkt.data[4]  = 0; // Flags

  if (systemState.fastClock.isStopped())
  {
    timePkt.data[4] |= TIME_FLAGS_DISP_FAST_HOLD;
  }

  timePkt.data[4] |= TIME_FLAGS_DISP_FAST;

  systemState.fastClock.getTime(&timePkt.data[5], &timePkt.data[6], &timePkt.data[7]);

  uint16_t mrbusFTRatio = systemState.fastClock.getRatio() / 100;
  timePkt.data[8] = 0xFF & (mrbusFTRatio>>8);
  timePkt.data[9] = mrbusFTRatio & 0xFF;
  return mrbus.txPktQueue->push(timePkt);
  return true;
}


bool sendMRBusVersionPacket(SystemState& systemState, MRBus& mrbus)
{
  // Send version packet
  MRBusPacket versionPkt;
  const char* const gitRev = GIT_REV;
  versionPkt.src = systemState.mrbusSrcAddrGet();
  versionPkt.dest = 0xFF;
  versionPkt.len = 14;
  versionPkt.data[0]  = 'v';
  versionPkt.data[1]  = 0x80;
  for(uint32_t i=0; i<6; i+=2)
  {
    char hexPair[3];
    memcpy(hexPair, gitRev + i, 2);
    hexPair[2] = 0;
    versionPkt.data[i/2 + 2] = strtol(hexPair, NULL, 16);
  }
  versionPkt.data[5]  = 1;
  versionPkt.data[6]  = 0;

  if (!systemState.isWifiConnected)
  {
    memcpy(versionPkt.data + 7, "NO WIFI", 7);
  } else if (!systemState.isCmdStnConnected) {
    memcpy(versionPkt.data + 7, "NO CMST", 7);
  } else if (systemState.isWifiConnected && systemState.isCmdStnConnected) {
    switch(systemState.cmdStnType)
    {
        case CMDSTN_DCCEX:
          memcpy(versionPkt.data + 7, "WF-DCCX", 7);
          break;
        case CMDSTN_JMRI:
          memcpy(versionPkt.data + 7, "WF-WTHR", 7);
          break;
        case CMDSTN_LNWI:
          memcpy(versionPkt.data + 7, "WF-LNWI", 7);
          break;
        case CMDSTN_ESU:
          memcpy(versionPkt.data + 7, "WF-ESU ", 7);
          break;
        default:
          memcpy(versionPkt.data + 7, "WF-UNKN", 7);
          break;
    }
  } else {
    memcpy(versionPkt.data + 7, "WF-XXX", 7);
  }

  return mrbus.txPktQueue->push(versionPkt);
}

void drawStatusScreen(SystemState& state)
{
  char lineBuf[24];
  char lpsText[16];
  const uint8_t spinnerChars[] = { '-', '\\', '|', '/' };
  static uint8_t spinnerNum = 0;
//     000000000011111111112
//     012345678901234567890
//  0:[a:LNWI    s T:nn B:aa] a=A/auto, C/config file (LNWI/ESU /WTHR/NONE) s=spinner nn=throttles connected aa=base addr  
//  1:[SSID-NAME-HERE-HERE-H] (scrolling)
//  2:[192.168.255.255:ppppp]
//  3:[R:-sss cc xxC xxxxlps] s=rssi, cc=channel

  // Update spinner
  spinnerNum = (spinnerNum + 1) % sizeof(spinnerChars);

  display.clrscr(false);

  memset(lineBuf, 0, sizeof(lineBuf));
  const char* cmdStnStr = "UNKN";
  switch(state.cmdStnType)
  {
    case CMDSTN_NONE:
      cmdStnStr = "NONE";
      break;
    case CMDSTN_LNWI:
      cmdStnStr = "LNWI";
      break;
    case CMDSTN_DCCEX:
      cmdStnStr = "DCCX";
      break;      
    case CMDSTN_JMRI:
      cmdStnStr = "WTHR";
      break;
    case CMDSTN_ESU:
      cmdStnStr = "ESU ";
      break;
    default:
      cmdStnStr = "UNKN";
      break;
  }

  snprintf(lineBuf, sizeof(lineBuf), "%c:%4.4s    %c T:%02d %c:%02d", state.isAutoNetwork?'A':'C', cmdStnStr, spinnerChars[spinnerNum], state.activeThrottles, state.isConflictingBasePresent()?'*':'B', state.baseAddress);
  display.putstr(lineBuf, 0, 0);

  if (0 == strlen(state.ssid))
  {
    snprintf(lineBuf, sizeof(lineBuf), "%-21.21s", "(Searching...)");
  } else {
    snprintf(lineBuf, sizeof(lineBuf), "%-21.21s", state.ssid);
  }
  display.putstr(lineBuf, 0, 1);

  if (state.isWifiConnected)
  {
    char ipBuffer[64];
    switch(state.ipDisplayLine)
    {
      case DISPLAY_IP_LOCAL:  // Two phases for 
      case DISPLAY_IP_LOCAL2:
        snprintf(lineBuf, sizeof(lineBuf), "L:%-19.19s", state.localIP.toString().c_str());
        break;
      case DISPLAY_IP_CMDSTN:
      case DISPLAY_IP_CMDSTN2:
        snprintf(ipBuffer, sizeof(ipBuffer), "%s:%d", state.cmdStnIP.toString().c_str(), state.cmdStnPort);
        snprintf(lineBuf, sizeof(lineBuf), "C:%-19.19s", ipBuffer);
        break;
      default:
        break;
    }
    state.ipDisplayLine = (IPLineDisplay)((state.ipDisplayLine + 1) % DISPLAY_IP_MAX_FIELDS);

  } else {
    snprintf(lineBuf, sizeof(lineBuf), "%-21.21s", "(No Network)");
  }
  display.putstr(lineBuf, 0, 2);

  uint32_t lps = state.loopCnt;
  state.loopCnt = 0;

  if (lps < 10000)
    snprintf(lpsText, sizeof(lpsText), "%04dl/s", lps);
  else if (lps >= 10000)
    snprintf(lpsText, sizeof(lpsText), "%03dkl/s", lps / 1000);
  else if (lps >= 100000)
    snprintf(lpsText, sizeof(lpsText), "%03dMl/s", lps / 1000000);

  snprintf(lineBuf, sizeof(lineBuf), "R:%02ddB  40C %7.7s", state.rssi, lpsText);
  display.putstr(lineBuf, 0, 3);

  display.refresh();
}

void loop() 
{
  systemState.loopCnt++;

  switch(mainLoopState)
  {
    case STATE_STARTUP:

    case STATE_DRAW_SPLASH_SCREEN:
      tmrSplashScreen.setup(2000);
      drawSplashScreen(systemState);
      tmrSplashScreen.reset();
      mainLoopState = STATE_WAIT_SPLASH_SCREEN;
      break;

    case STATE_WAIT_SPLASH_SCREEN:
      if (tmrSplashScreen.test(false))
      {
        mainLoopState = STATE_MAIN_LOOP;

        // Print a bunch of diagnostic header info to the serial console
        Serial.printf("[SYS]: Iowa Scaled Engineering\n");
        Serial.printf("[SYS]: MRBW-WIFI\n");
        Serial.printf("[SYS]: IDF Ver:  [%s]\n", esp_get_idf_version());
        Serial.printf("[SYS]: MAC Addr: [%02X:%02X:%02X:%02X:%02X:%02X]\n", 
          systemState.macAddr[0], systemState.macAddr[1], systemState.macAddr[2],
          systemState.macAddr[3], systemState.macAddr[4], systemState.macAddr[5]);

        esp_chip_info_t chip_info;
        esp_chip_info(&chip_info);
        Serial.printf("[SYS]: ESP32S2 rev %d \n", chip_info.revision);
        Serial.printf("[SYS]: Reset Reason: [%s]\n", systemState.resetReasonStringGet());
      }
      break;

    case STATE_MAIN_LOOP:
      if (tmrStatusScreenUpdate.test(true))
      {
        uint32_t color = WS2812_RED;
        esp_task_wdt_reset();

        // Will only send time if we have a fast time source
        sendMRBusTimePacket(systemState, mrbus);

        Serial.printf("[SYS]: TICK %05us stack: %d heap:%d Wifi=%c CmdStn=%c\n", (uint32_t)(esp_timer_get_time() / 1000000), uxTaskGetStackHighWaterMark(NULL), xPortGetFreeHeapSize(), systemState.isWifiConnected?'Y':'N', systemState.isCmdStnConnected?'Y':'N');

        systemState.baseAddress = switches.baseAddressGet();
        mrbus.setAddress(systemState.baseAddress + 0xD0); // MRBus address for the base is switches + 0xD0 offset
        systemState.rssi = WiFi.RSSI();

        systemState.activeThrottles = 0;
        for(uint32_t thrNum=0; thrNum < MAX_THROTTLES; thrNum++)
          if (throttles[thrNum].isActive())
            systemState.activeThrottles++;

        drawStatusScreen(systemState);

        if (systemState.isWifiConnected && systemState.isCmdStnConnected)
        {
          // Total abuse of an unsuspecting, innocent variable to get a 1 second phase clock
          if (systemState.isConflictingBasePresent() && systemState.ipDisplayLine & 0x01)
            color = WS2812_CYAN;
          else
            color = WS2812_GREEN;

        }
        else if (systemState.isWifiConnected)
          color = WS2812_YELLOW;
          
        ws2812Set(color);
        // Send our version and status out every second
        sendMRBusVersionPacket(systemState, mrbus);
      }
      mrbus.processSerial();

      if (!systemState.isWifiConnected || !systemState.isCmdStnConnected)
      {
        mrbus.rxPktQueue->flush();
      }

      // Check wifi network - if we don't have it, try to get it
      if (!systemState.isWifiConnected)
      {
        bool networkFound = systemState.wifiScan();
        systemState.localIP.fromString("0.0.0.0");
        systemState.isCmdStnConnected = false;

        if (networkFound) // Can either be because search found one or not autconfig
        {
          // Try to connect to the network we found
          Serial.printf("[SYS]: Starting connection to [%s] [%s]\n", systemState.ssid, systemState.password);
          WiFi.begin(systemState.ssid, systemState.password);

          // FIXME - put timeout here
          while(WiFi.status() != WL_CONNECTED)
          {
            delay(100);
          }
          Serial.printf("[SYS]: Connected to wifi network [%s]\n", systemState.ssid);
          WiFi.setAutoReconnect(true);
        }

        // Did we connect?  If so, change our indication to wifi connected and go back around the loop
        if(WiFi.status() == WL_CONNECTED)
        {
          systemState.localIP = WiFi.localIP();
          systemState.isWifiConnected = true;
          systemState.isCmdStnConnected = false;
          MDNS.begin(systemState.hostname);
          return;
        }
      }
      else if (WiFi.status() != WL_CONNECTED)  // This implies that systemState.isWifiConnected is true
      {
        Serial.printf("[SYS]: Wireless Dropped, Resetting\n");
        MDNS.end();
        systemState.localIP.fromString("0.0.0.0");
        systemState.isWifiConnected = false;
        systemState.cmdStnDisconnect();

      }

      if (!systemState.isWifiConnected || tmrStatusScreenUpdate.test(false))
        return; // Out we go - can't do squat without a wifi connection, or maybe we need to do a screen refresh

      if (systemState.isCmdStnConnected)
      {
        // Just make sure we're really still connected
        if (!systemState.cmdStnConnection.connected())
        {
          Serial.printf("[SYS]: Stopping command station socket connection\n\n");
          Serial.flush();
          sys_delay_ms(1000);
          systemState.cmdStnConnection.stop();

          if (NULL != systemState.cmdStn)
          {
            Serial.printf("[SYS]: Deleting disconnected command station\n\n");
            Serial.flush();
            sys_delay_ms(1000);
            systemState.cmdStnDisconnect();
            return; // Just start the loop again.
          }
        }
      }

      if (!systemState.isCmdStnConnected)
      {
        // Try to build a connection
        if (!systemState.cmdStnIPSetup())  // Do all the logic about merging configuration with auto-discovery
          return;  // No IP found for a command station, on with life - return from loop() and start over
        
        Serial.printf("[SYS]: Trying to connect %s:%d\n", systemState.cmdStnIP.toString().c_str(), systemState.cmdStnPort);
        bool connectSuccessful = systemState.cmdStnConnection.connect(systemState.cmdStnIP, systemState.cmdStnPort, 1000);
        Serial.printf("[SYS]: Connect successful = %c\n", connectSuccessful?'Y':'N');

        if (connectSuccessful)
        {
          systemState.isCmdStnConnected = true;
          char macBuffer[16];
          snprintf(macBuffer, sizeof(macBuffer)-1, "%02X%02X", systemState.macAddr[4], systemState.macAddr[5]);
          uint32_t quirkFlags = 0;

          // Nuke any throttles that may be left over from last time.
          for(uint32_t thrNum=0; thrNum<MAX_THROTTLES; thrNum++)
          {
            throttles[thrNum].initialize(MRBUS_THROTTLE_BASE_ADDR + thrNum, systemState.debugLvlMRBus);
          }

          // Create command station object
          switch(systemState.cmdStnType)
          {
            case CMDSTN_JMRI:
            case CMDSTN_DCCEX:
            case CMDSTN_LNWI:
              // These are all variants of the WiThrottle protocol, but all implement it just a little differently
              // The main difference right now is that DCC-EX and LNWI do not support the "force function" ('f') command
              //  which is bloody annoying
              if (CMDSTN_LNWI == systemState.cmdStnType)
                quirkFlags |= WITHROTTLE_QUIRK_LNWI;
              else if (CMDSTN_DCCEX == systemState.cmdStnType)
                quirkFlags |= WITHROTTLE_QUIRK_DCCEX;

              systemState.cmdStn = new WiThrottle(macBuffer);
              systemState.cmdStn->begin(systemState.cmdStnConnection, quirkFlags, systemState.debugLvlCommandStation);
              if (FC_SOURCE_CMDSTN == systemState.fcSource)
              {
                if (systemState.cmdStn->fastClockConnect(&systemState.fastClock))
                {
                  systemState.fastClock.enable();
                } else {
                  systemState.fastClock.disable();
                }
              }
              break;

            case CMDSTN_ESU:
              systemState.cmdStn = new ESUCabControl;
              systemState.cmdStn->begin(systemState.cmdStnConnection, 0, systemState.debugLvlCommandStation);
              break;

            default: // Do nothing, don't know what it is
              break;
          }
        }
      }

      if (!systemState.isCmdStnConnected || tmrStatusScreenUpdate.test(false))
        return;

      systemState.cmdStn->update();

      // If we're here, we should have a command station connected
      while(!mrbus.rxPktQueue->isEmpty())
      {
        MRBusPacket pkt;
        mrbus.rxPktQueue->pop(pkt);
        /*Serial.printf("Pkt [%02x->%02x (%d bytes) ", pkt.src, pkt.dest, pkt.len);
        for(uint32_t k = 0; k<pkt.len; k++)
          Serial.printf("%02x ", pkt.data[k]);
        Serial.printf("]\n");*/

        if (pkt.src == systemState.mrbusSrcAddrGet())
        {
          // Ouch, conflicting base station detected
          systemState.registerConflictingBase();
          continue;
        }

        if (pkt.dest == systemState.mrbusSrcAddrGet() && pkt.data[0] == 'S' && pkt.len == 15
          && (pkt.src >= MRBUS_THROTTLE_BASE_ADDR && pkt.src < MRBUS_THROTTLE_BASE_ADDR + MAX_THROTTLES))
        {
//          Serial.printf("Throttle pkt [%02x->%02x  %02d]\n", pkt.src, pkt.dest, pkt.len);
          uint8_t throttleNum = pkt.src - MRBUS_THROTTLE_BASE_ADDR;
          throttles[throttleNum].update(systemState.cmdStn, pkt);
        }
      }

      // Check for dead throttles and remove them
      for(uint32_t thrNum=0; thrNum < MAX_THROTTLES; thrNum++)
      {
        if (throttles[thrNum].isActive() && throttles[thrNum].isExpired(THROTTLE_TIMEOUT_SECONDS))
        {
          throttles[thrNum].disconnect(systemState.cmdStn);
        }
      }
      break;

    default:
      break;

  }
}

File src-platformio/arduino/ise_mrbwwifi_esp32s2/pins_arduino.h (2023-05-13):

#ifndef Pins_Arduino_h
#define Pins_Arduino_h

#include <stdint.h>


#define USB_VID            0x1209
#define USB_PID            0x6571
#define USB_MANUFACTURER   "Iowa Scaled Engineering"
#define USB_PRODUCT        "MRBW-WIFI v1.1"
#define USB_SERIAL         ""   // Empty string for MAC adddress

#define EXTERNAL_NUM_INTERRUPTS 46
#define NUM_DIGITAL_PINS        48
#define NUM_ANALOG_INPUTS       20

#define analogInputToDigitalPin(p)  (((p)<20)?(analogChannelToDigitalPin(p)):-1)
#define digitalPinToInterrupt(p)    (((p)<48)?(p):-1)
#define digitalPinHasPWM(p)         (p < 46)

#define LED_BUILTIN     42

#define PIN_NEOPIXEL    45
#define NEOPIXEL_NUM    1

#define PIN_BUTTON1     0  // BOOT0 switch

static const uint8_t TX = 5;
static const uint8_t RX = 6;

static const uint8_t SDA = 33;
static const uint8_t SCL = 34;

static const uint8_t SS    = 42;
static const uint8_t MOSI  = 35;
static const uint8_t SCK   = 36;
static const uint8_t MISO  = 37;

static const uint8_t A0 = 17;
static const uint8_t A1 = 18;
static const uint8_t A2 = 1;
static const uint8_t A3 = 2;
static const uint8_t A4 = 3;
static const uint8_t A5 = 4;
static const uint8_t A6 = 5;
static const uint8_t A7 = 6;
static const uint8_t A8 = 7;
static const uint8_t A9 = 8;
static const uint8_t A10 = 9;
static const uint8_t A11 = 10;
static const uint8_t A12 = 11;
static const uint8_t A13 = 12;
static const uint8_t A14 = 13;
static const uint8_t A15 = 14;
static const uint8_t A16 = 15;
static const uint8_t A17 = 16;
static const uint8_t A18 = 19;
static const uint8_t A19 = 20;


static const uint8_t T1 = 1;
static const uint8_t T2 = 2;
static const uint8_t T3 = 3;
static const uint8_t T4 = 4;
static const uint8_t T5 = 5;
static const uint8_t T6 = 6;
static const uint8_t T7 = 7;
static const uint8_t T8 = 8;
static const uint8_t T9 = 9;
static const uint8_t T10 = 10;
static const uint8_t T11 = 11;
static const uint8_t T12 = 12;
static const uint8_t T13 = 13;
static const uint8_t T14 = 14;

static const uint8_t DAC1 = 17;
static const uint8_t DAC2 = 18;

#endif /* Pins_Arduino_h */

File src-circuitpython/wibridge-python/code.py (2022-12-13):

import time
import re

import board
import digitalio
import busio
import mrbus
import microcontroller
import ipaddress
import wifi
import socketpool

import withrottle
import esu
import MRBusThrottle
from switches import Switches
from screen import Screen
from systemstate import SystemState
from microcontroller import watchdog
from watchdog import WatchDogMode

import gc

gc.collect()
print("Initial memory %d" % (gc.mem_free()))

debug = False

uart = busio.UART(board.IO17, board.IO18, baudrate=115200, timeout=0, receiver_buffer_size = 1024)
uart.reset_input_buffer()
i2c = busio.I2C(board.SCL, board.SDA, frequency=400000)
dipSwitches = Switches()
mrbee = mrbus.mrbus(0x03, uart)

watchdog.timeout = 30
watchdog.mode = WatchDogMode.RESET
watchdog.feed()


screen = Screen()
screen.init(i2c)

screen.splash_screen()
splashStart = time.monotonic()

while time.monotonic() - 1 < splashStart:
  pass

sysState = SystemState()
sysState.readConfigurationFile("/config.txt")

if not sysState.configurationValid:
  screen.clearScreen()
#     000000000011111111112
#     012345678901234567890
#     Configuration Invalid
  screen.writeBufferedText("Configuration Invalid", 0, 0)
  screen.writeBufferedText(sysState.configurationError[0:22], 0, 1)
  screen.writeBufferedText(sysState.configurationError[22:43], 0, 1)
  screen.writeBufferedText(sysState.configurationError[43:64], 0, 1)
  screen.flushBufferedText()
  while True:
    pass

screen.writeText('C', 10, 2)

wifi.radio.hostname = sysState.hostName

if sysState.isAutoNetwork:
  sysState.scanForNetworks()

screen.writeText('N', 11, 2)

while time.monotonic() - 5 < splashStart:
  pass


lastpkt = time.monotonic()

print("My MAC addr:", [hex(i) for i in wifi.radio.mac_address])

loopCnt = 0
displayUpdateTime = 0
throttles = { }
lastLoopUpdate = time.monotonic() - 2
lastStatusTime = time.monotonic() - 2
screen.clearScreen()

gitver = [ 0x12, 0x34, 0x56 ]

def serverFind(pool, timeout, port):
  """Given a port, this searches the local class C subnet for anything with that port open."""
  conn = pool.socket(socketpool.SocketPool.AF_INET, socketpool.SocketPool.SOCK_STREAM)
  (o1,o2,o3,o4) = ("%s" % sysState.ipv4).split('.')

  print("Starting server scan on subnet (%s.%s.%s.255)" % (o1, o2, o3))
  for i in range(1,255):
    scanIP = "%s.%s.%s.%d" % (o1, o2, o3, i)
    conn.settimeout(timeout)
    try:
      print("Trying %s:%d" % (scanIP, port))
      conn.connect((scanIP, port))
      return (scanIP, conn)
    except Exception as e:
      time.sleep(0.1)
      print(e)

  return None

while True:
  loopCnt += 1
  watchdog.feed()
  currentTime = time.monotonic()
  # Housekeeping Tasks - Run on a Schedule
  
  # Every second, update the screen
  if sysState.forceScreenUpdate or currentTime > lastLoopUpdate + 1:
    gc.collect()  # Not sure why, but it seems to be less crashy if the gc runs regularly rather than on demand
    sysState.lps = loopCnt / (currentTime - lastLoopUpdate)
    sysState.throttlesConnected = len(throttles)
    lastLoopUpdate = currentTime

    if wifi.radio.ap_info is not None:
      sysState.rssi = wifi.radio.ap_info.rssi
    sysState.baseAddr = dipSwitches.getBaseAddr()
    mrbee.addr = sysState.getMrbusBaseAddr()
    
    screen.status_screen(sysState)
    loopCnt = 0
    sysState.forceScreenUpdate = False

  # Send periodic version packets so throttles see us, even if we aren't useful
  if currentTime > lastStatusTime + sysState.statusBroadcastIntervalSeconds:
    if debug:
      print("PT-BRIDGE: Sending status packet")
    statusPacket = [ ord('v'), 0x80, gitver[2], gitver[1], gitver[0], 1, 0 ] + sysState.getInterfaceVerPktText()
    mrbee.sendpkt(0xFF, statusPacket)
    lastStatusTime = currentTime

  # If we don't have a wifi connection, the first order of business is to get one
  if not sysState.isWifiConnected:
    sysState.isCmdStnConnected = False

    if sysState.isAutoNetwork and sysState.networkSSID is None:
      sysState.scanForNetworks()

    if sysState.networkSSID is None:
      continue

    if debug:
      print("My MAC addr:", [hex(i) for i in wifi.radio.mac_address])
      print("Connecting to [%s] - pass [%s]" % (sysState.networkSSID, sysState.networkPassword))
    
    try:
      if sysState.networkPassword == "":
        wifi.radio.connect(sysState.networkSSID)
      else:
        wifi.radio.connect(sysState.networkSSID, sysState.networkPassword)

      pool = socketpool.SocketPool(wifi.radio)
      print("My IP address is", wifi.radio.ipv4_address)
      print("My gateway is", wifi.radio.ipv4_gateway)

      pingTime = wifi.radio.ping(wifi.radio.ipv4_gateway)
      if None != pingTime:
        print("ping is %d" % (pingTime))

      sysState.ipv4 = wifi.radio.ipv4_address
      sysState.ipv4_gateway = wifi.radio.ipv4_gateway
      sysState.isWifiConnected = True

    except Exception as e:
      print("Connect loop:", e)
      time.sleep(0.1)
      sysState.isWifiConnected = False

    # Head to the top of the loop to get the screen updates
    continue

  # At this point, wifi is good, see if we need to build the command station connection

  if not sysState.isCmdStnConnected:
    openSocket = None
    cmdStationIP = sysState.cmdStationIP
    cmdStationPort = sysState.cmdStationPort

    if sysState.cmdStationType in ['lnwi', 'withrottle'] and cmdStationPort is None:
      cmdStationPort = 12090
    elif sysState.cmdStationType in ['esu'] and cmdStationPort is None:
      cmdStationPort = 15471

    if cmdStationIP is None:
      # Go figure it out
      if sysState.cmdStationType == 'lnwi':
        # LNWIs are always on x.x.x.1, usually 192.168.(channel).1
        (o1, o2, o3, o4) = ("%s" % sysState.ipv4).split('.')
        cmdStationIP = "%s.%s.%s.1" % (o1, o2, o3)
      else:
        # Gotta go scan the subnet
        result = serverFind(pool, 0.2, cmdStationPort)
        if result is not None:
          (cmdStationIP, openSocket) = result
        else:
          print("cmdStationIP not found")
          continue


    print("cmdStationIP = %s:%d" % (cmdStationIP, cmdStationPort))
    if cmdStationIP is None:
      continue

    if sysState.cmdStationType == 'lnwi':
      try:
        commandStation = withrottle.WiThrottleConnection(pool)
        commandStation.connect(cmdStationIP, cmdStationPort, "LNWI", conn=openSocket)
        while uart.read(1024) is not None: # Flush RX buffer
          pass
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

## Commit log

2022-04-10 Well, it's a start of a schematic
    [mrbw-wifi.sch]
2022-04-27 Add PCB file, update schematic
    [mrbw-wifi.sch]
2022-05-03 Change to mini USB B jack
    [mrbw-wifi.sch]
2022-05-03 Change 1117 to SOT223
    [mrbw-wifi.sch]
2022-05-14 Fix pinout of ESP32-S2-SOLO
2022-05-15 Sent to fab 5/14/2022
    [mrbw-wifi.bottom.gbr, mrbw-wifi.bottommask.gbr, mrbw-wifi.bottompaste.gbr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]
2022-06-09 Reverse DIN/DOUT wires for XBee programming Add + signs to LEDs
    [mrbw-wifi.sch]
2022-06-09 Power WS2812B off +5V, not +3.3V
    [mrbw-wifi.sch]
2022-07-10 Most up to date version of the python code
    [config.txt]
2022-09-04 Fix issue where if the ISE logo isn't opened in binary, it doesn't work on CP 8+
    [screen.py]
2022-09-04 New config parser to make it ini like (key = value)
    [config.txt]
2022-09-04 Add a factory reset mode in boot.py
    [boot.py]
2022-09-04 Add pieces for building circuitpython image
2022-10-16 PG version 1.1
    [mrbw-wifi.bottom.gbr, mrbw-wifi.bottommask.gbr, mrbw-wifi.bottompaste.gbr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]
2022-11-22 Spacer for screen
    [screen-spacer v1.stl]
2022-11-22 Removed reset button clause
2022-12-04 Add support for RGB LED and enhance bootloader to rebuild from bin files dropped on the drive
2022-12-04 Change board build to free up some space Update base image to essentially 1.0.1
2022-12-04 Add 10 seconds of flashing blue before factory resetting the file system
    [boot.py]
2022-12-04 Update boot.py to check the factory reset pin one more time before resetting the filesystem
    [boot.py]
2022-12-09 Improve serial handling - add initialization to reset the input buffer, which turns out is really important for this thing not being dog slow, and add ability to get more than one packet at a time ou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
    [code.py, mrbus.py]
2022-12-12 Add a forced gc to the code - made the ntp server less crashy and doesn't seem to screw up performance that badly
    [code.py]
2022-12-31 Fix broken ESU password
    [systemstate.py]
2023-01-01 Add something to deal with concatenated responses. Probably not a final fix, but better than failing and building up in the buffer
    [esu.py]
2023-03-18 Move python source out of main src directory
    [config.txt]
2023-03-19 Move header files, implement status screen, fix switches
    [main.cpp, switches.cpp]
2023-04-04 More work - throttles and command stations started
2023-04-04 More fixes for throttle acquisition/release
    [main.cpp]
2023-04-10 Some initial socket code seems to be working with the withrottle stuff
2023-04-16 Various fixes, refactor to remove circular CommandStation MRBusThrottle dependency
    [ESUCabControl.cpp, WiThrottle.cpp]
2023-05-13 Board updates, minor code stuff
    [partitions-4MBLA-tinyuf2.csv, partitions-4MBLA.csv]
2023-05-15 Add power control to esu driver
2023-05-20 Fix withrottle not storing cab letter. Increment to v1.0.2
    [ESUCabControl.cpp, WiThrottle.cpp]
2023-05-25 Fix crash issue on withrottle wifi dropping
    [WiThrottle.cpp, main.cpp, systemState.cpp]
2023-05-29 Fix the issue where the FR switch didn't work
    [main.cpp, switches.cpp]
2023-05-29 Add screen top cover STL and gcode
    [screen-top v4.stl]
